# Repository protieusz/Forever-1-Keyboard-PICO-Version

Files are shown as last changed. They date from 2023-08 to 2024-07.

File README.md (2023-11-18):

# Forever-1-Keyboard-PICO-Version
Forever-1 Inspired by policum's GRIN QUERN 38 keys keyboard powered by PICO Raspberry with giant 60mm rotary encoder with 40mm Cirque trackpad

Got featured on [Keyboard Builder's Digest (KBD News)](https://kbd.news/FOREVER-1-2107.html)

This pcb design is proudly sponsored by PCBWay, your solution to all your prototype pcb needs. PCBWay customer service dept are very proactive on making things right if there are issues with the production.  

Part of the design was assisted by policum, the designer for GRIN QUERN which the Forever-1 is inspired from.

**Update Nov 18, 2023:** The gerber production files have been uploaded. Print at your own risk. Please follow the license useage and don't be an ass.  Lots of advance soldering technique is required. No support will be given.
BOM list is inside the build guide excel file along with the links.

Update Aug 30, 2023: PCB from PCBWay has arrived. Keyboard has been assembled except for the case and waiting for the nylon knob print.

~~This design will be close source for now. It might be release in the future.~~

Final Build Sept 1, 2023

















Partial build Aug 30, 2023





















































PCB is currently is in print as of Aug 21, 2023.  Build pictures coming soon.

A mock up of the final product






















# License

</a></p>

You are free to:

Share — copy and redistribute the material in any medium or format

Adapt — remix, transform, and build upon the material

The licensor cannot revoke these freedoms as long as you follow the license terms.
Under the following terms:

Attribution — You must give appropriate credit, provide a link to the license, and indicate if changes were made. You may do so in any reasonable manner, but not in any way that suggests the licensor endorses you or your use.

NonCommercial — You may not use the material for commercial purposes.

ShareAlike — If you remix, transform, or build upon the material, you must distribute your contributions under the same license as the original.

No additional restrictions — You may not apply legal terms or technological measures that legally restrict others from doing anything the license permits.

Forever-1 by ProtieusKeebs is licensed under [CC BY-NC-SA 4.0](https://creativecommons.org/licenses/by-nc-sa/4.0/?ref=chooser-v1)

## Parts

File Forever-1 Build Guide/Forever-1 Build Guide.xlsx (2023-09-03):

FOREVER-1 Build Guilde
BOM List:
Item Number | Item Name | Part Number | Web Link
1 | Raspberry PICO mcu | Green USB C | Pico Raspberry Green USB C (https://www.aliexpress.com/item/1005003371056277.html)
2 | Bourn’s PER60 mm Encoder | PER601-P117-N0015 | Encoders Encoders 60MM LOW PROFILE ENCODER (https://www.mouser.ca/ProductDetail/652-PER601P117N0015)
3 | Cirque 40mm Trackpad | TM040040-2024-303 | Cirque 40mm trackpad (https://www.mouser.ca/ProductDetail/355-TM0400402024-303)
4 | SK6812 mini e RGB (3-4 pcs) optional |  | SK6812 mini e (https://www.aliexpress.com/item/1005004249903121.html)
5 | Wires 26 AWG (5meters, recommend getting 6 different colors) |  | Wires 26 AWG 5 meters (https://www.aliexpress.com/item/1005001869989189.html)
6 | Diodes smd 38 pcs |  | Diodes SMD 1N4148 SOD-123 (https://www.aliexpress.com/item/1005002936094696.html)
7 | 38 Switches |  | Your choice
8 | Cherry/OEM keycaps (Due to rotations, MT3 profiles will rub) |  | Your choice
9 | 3M double side tape for securing the trackpad to the support |  | Amazon or Aliexpress. Common product
10 | Acrylic glue or whatever glue to secure the tackpad support structure to the pcb |  | Acrylic glue (https://www.aliexpress.com/item/1005004560711687.html)
11 | M2x2x3.2 hot inserts (11pcs) |  | M2x2x3.2 Hot Inserts (https://www.aliexpress.com/item/1005004629326869.html)
12 | M2 5mm screws (11pcs) |  | M2 5mm screws (https://www.aliexpress.com/item/32976597416.html)

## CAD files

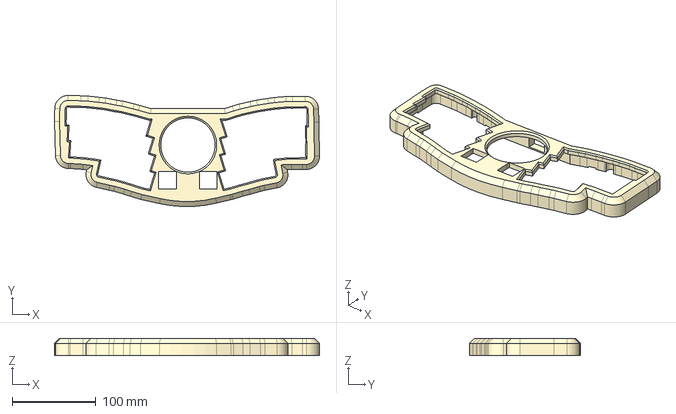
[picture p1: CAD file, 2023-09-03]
Forever-1 Full Case.step
316.6 x 132.6 x 20.9 mm

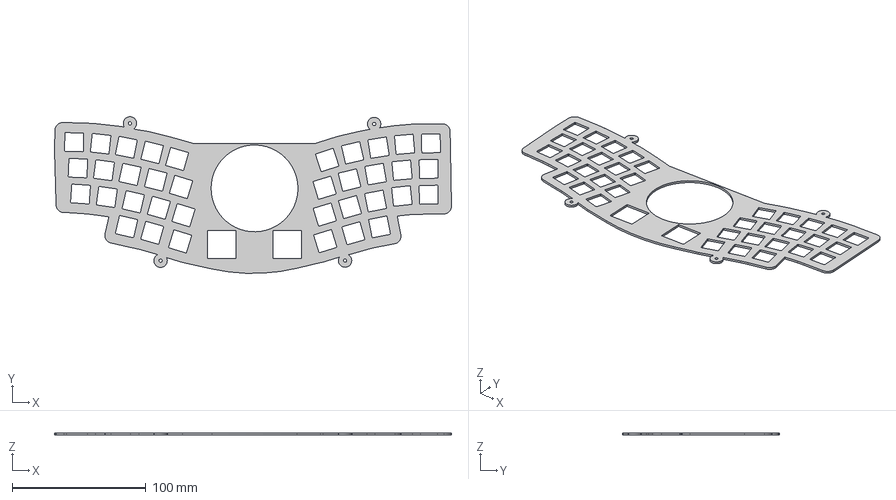
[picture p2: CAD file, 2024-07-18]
Full Switch Plate/Forever-1 Full Switch Plate.step
296.6 x 117.0 x 1.60 mm

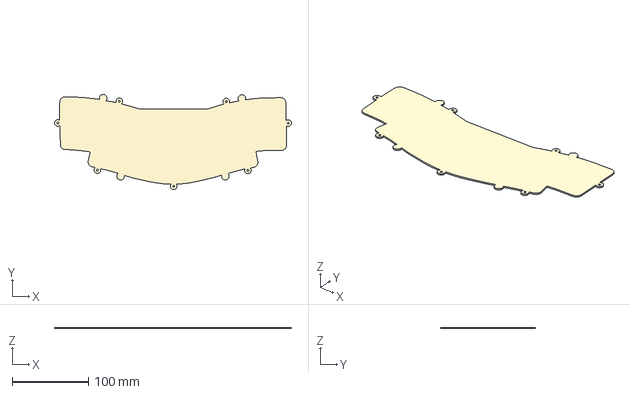
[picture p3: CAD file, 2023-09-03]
Forever-1 full bottom plate.step
311.6 x 125.2 x 1.60 mm

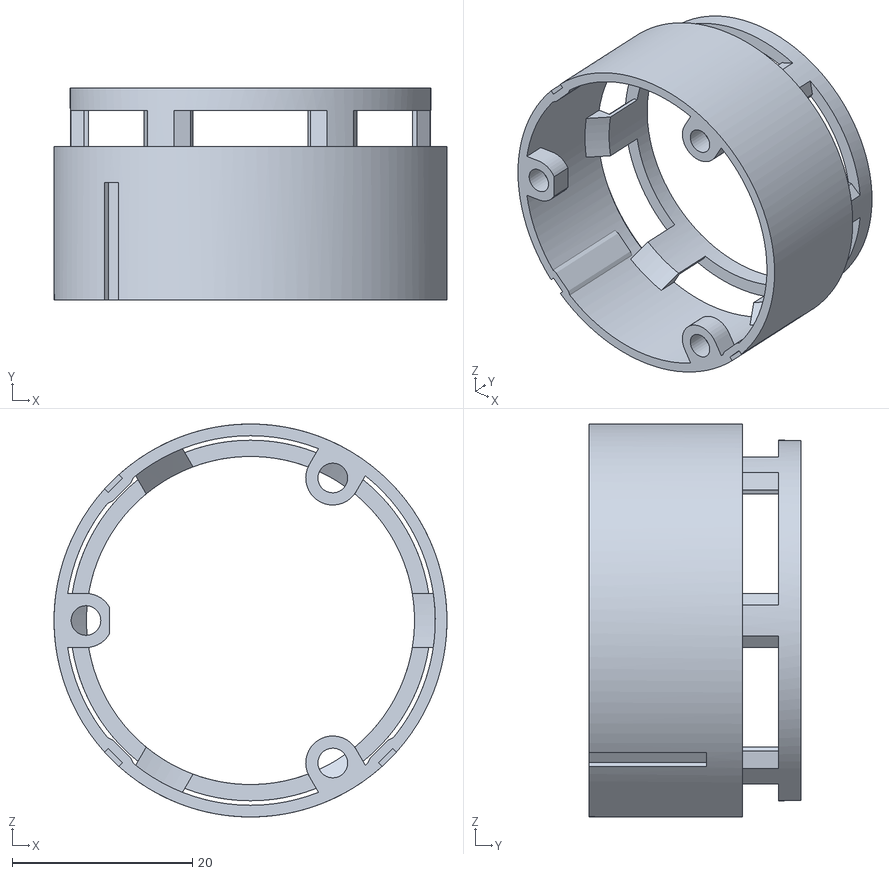
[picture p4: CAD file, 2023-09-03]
Center Piece Support Parts/Bournsper60knobstand.stl
43.6 x 23.5 x 43.6

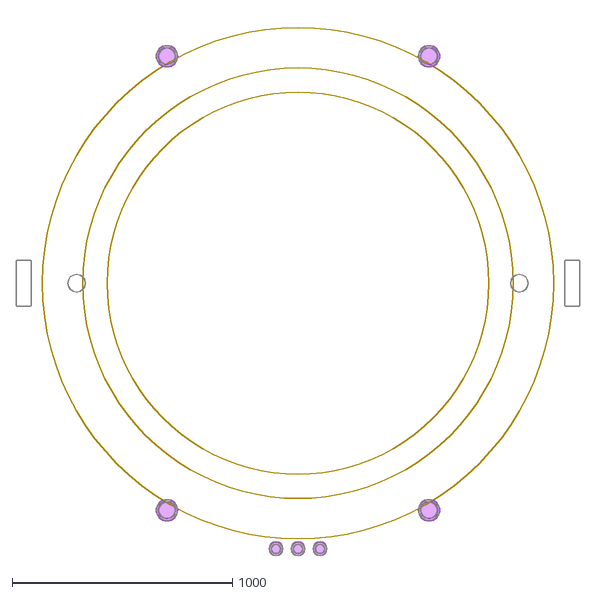
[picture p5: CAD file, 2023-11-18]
GerberRev1/PER601_2023-08-14.dxf
2557.0 x 2447.8

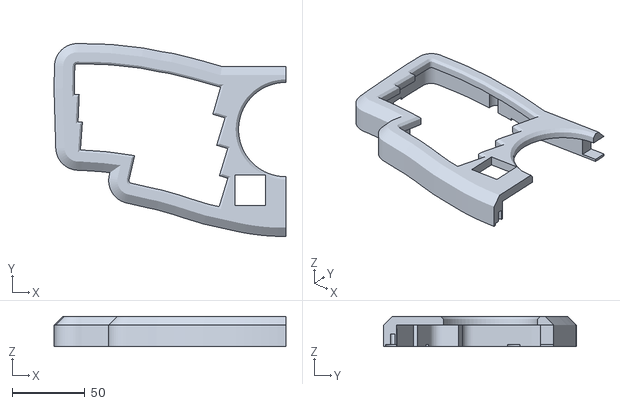
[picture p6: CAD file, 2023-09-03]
Split STLs/Forever1CaseLEFT.stl
159.6 x 132.7 x 20.9

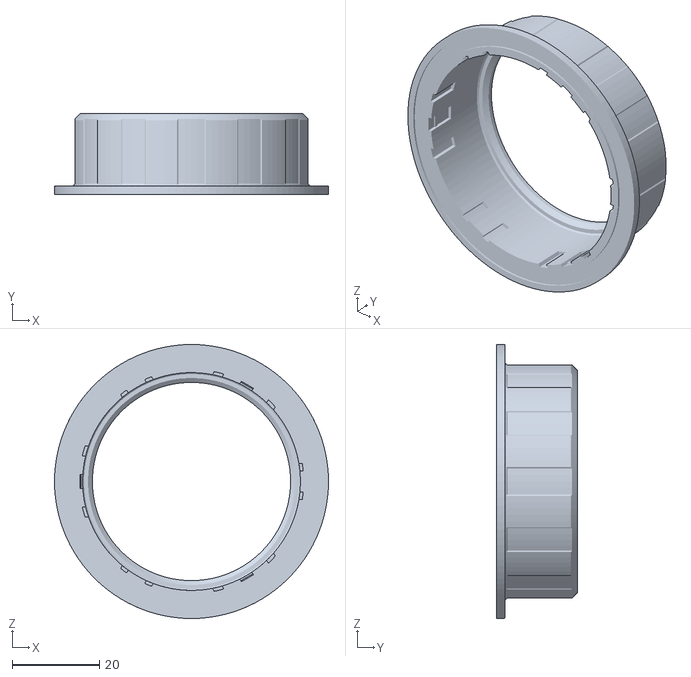
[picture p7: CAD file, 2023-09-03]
Center Piece Support Parts/Bournsper60knob.stl
62.9 x 18.6 x 62.9

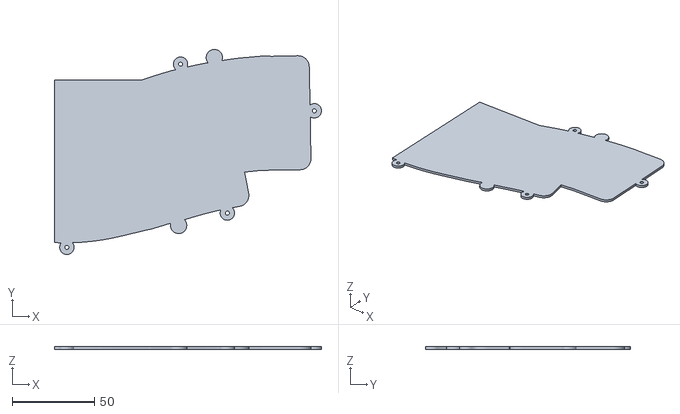
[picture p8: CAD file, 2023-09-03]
Split STLs/Forever1BottomplateRIGHT.stl
162.4 x 124.8 x 1.60

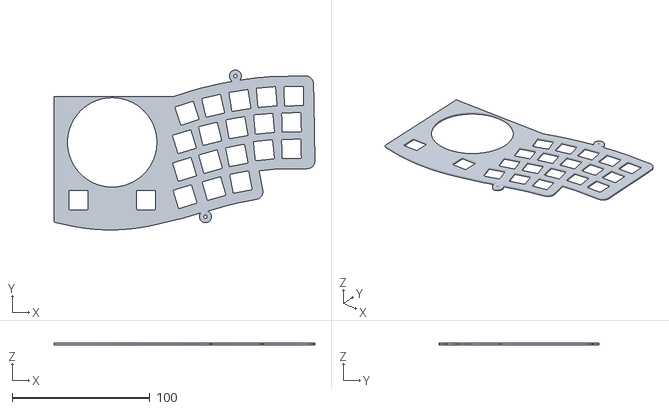
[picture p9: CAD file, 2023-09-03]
Split STLs/Forever1SwitchPlateRIGHT.stl
189.4 x 116.0 x 1.50

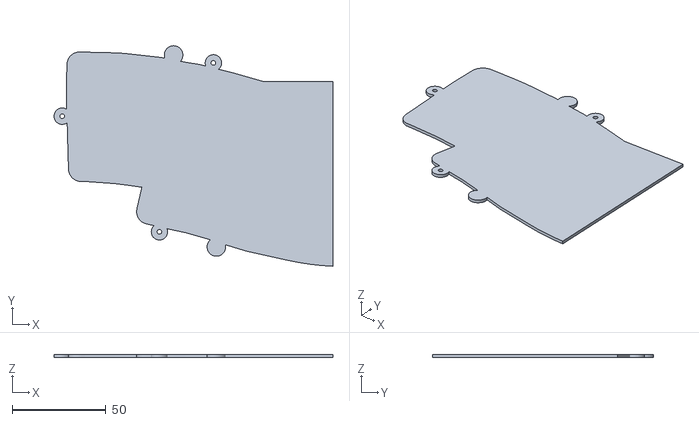
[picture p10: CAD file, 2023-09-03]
Split STLs/Forever1BottomplateLEFT.stl
149.2 x 117.9 x 1.60

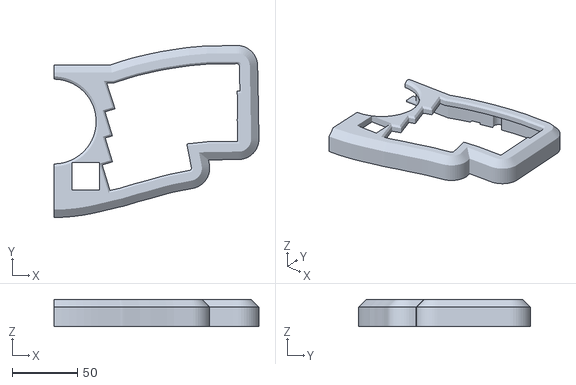
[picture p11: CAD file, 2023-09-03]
Split STLs/Forever1CaseRIGHT.stl
157.0 x 131.8 x 20.9

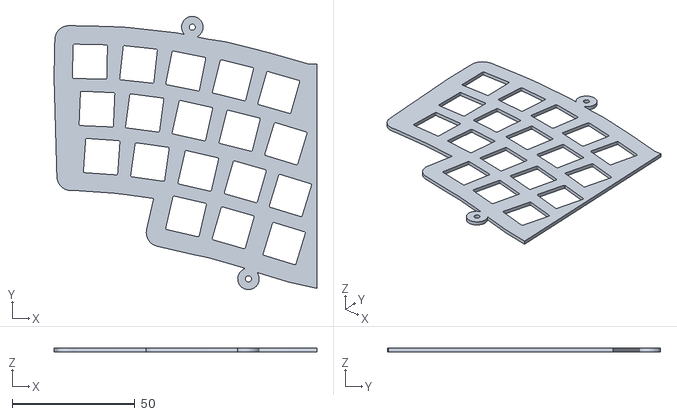
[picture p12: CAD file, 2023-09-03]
Split STLs/Forever1SwitchPlateLEFT.stl
107.2 x 111.4 x 1.50

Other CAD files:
Full Switch Plate/Forever-1 Full Switch Plate.stl

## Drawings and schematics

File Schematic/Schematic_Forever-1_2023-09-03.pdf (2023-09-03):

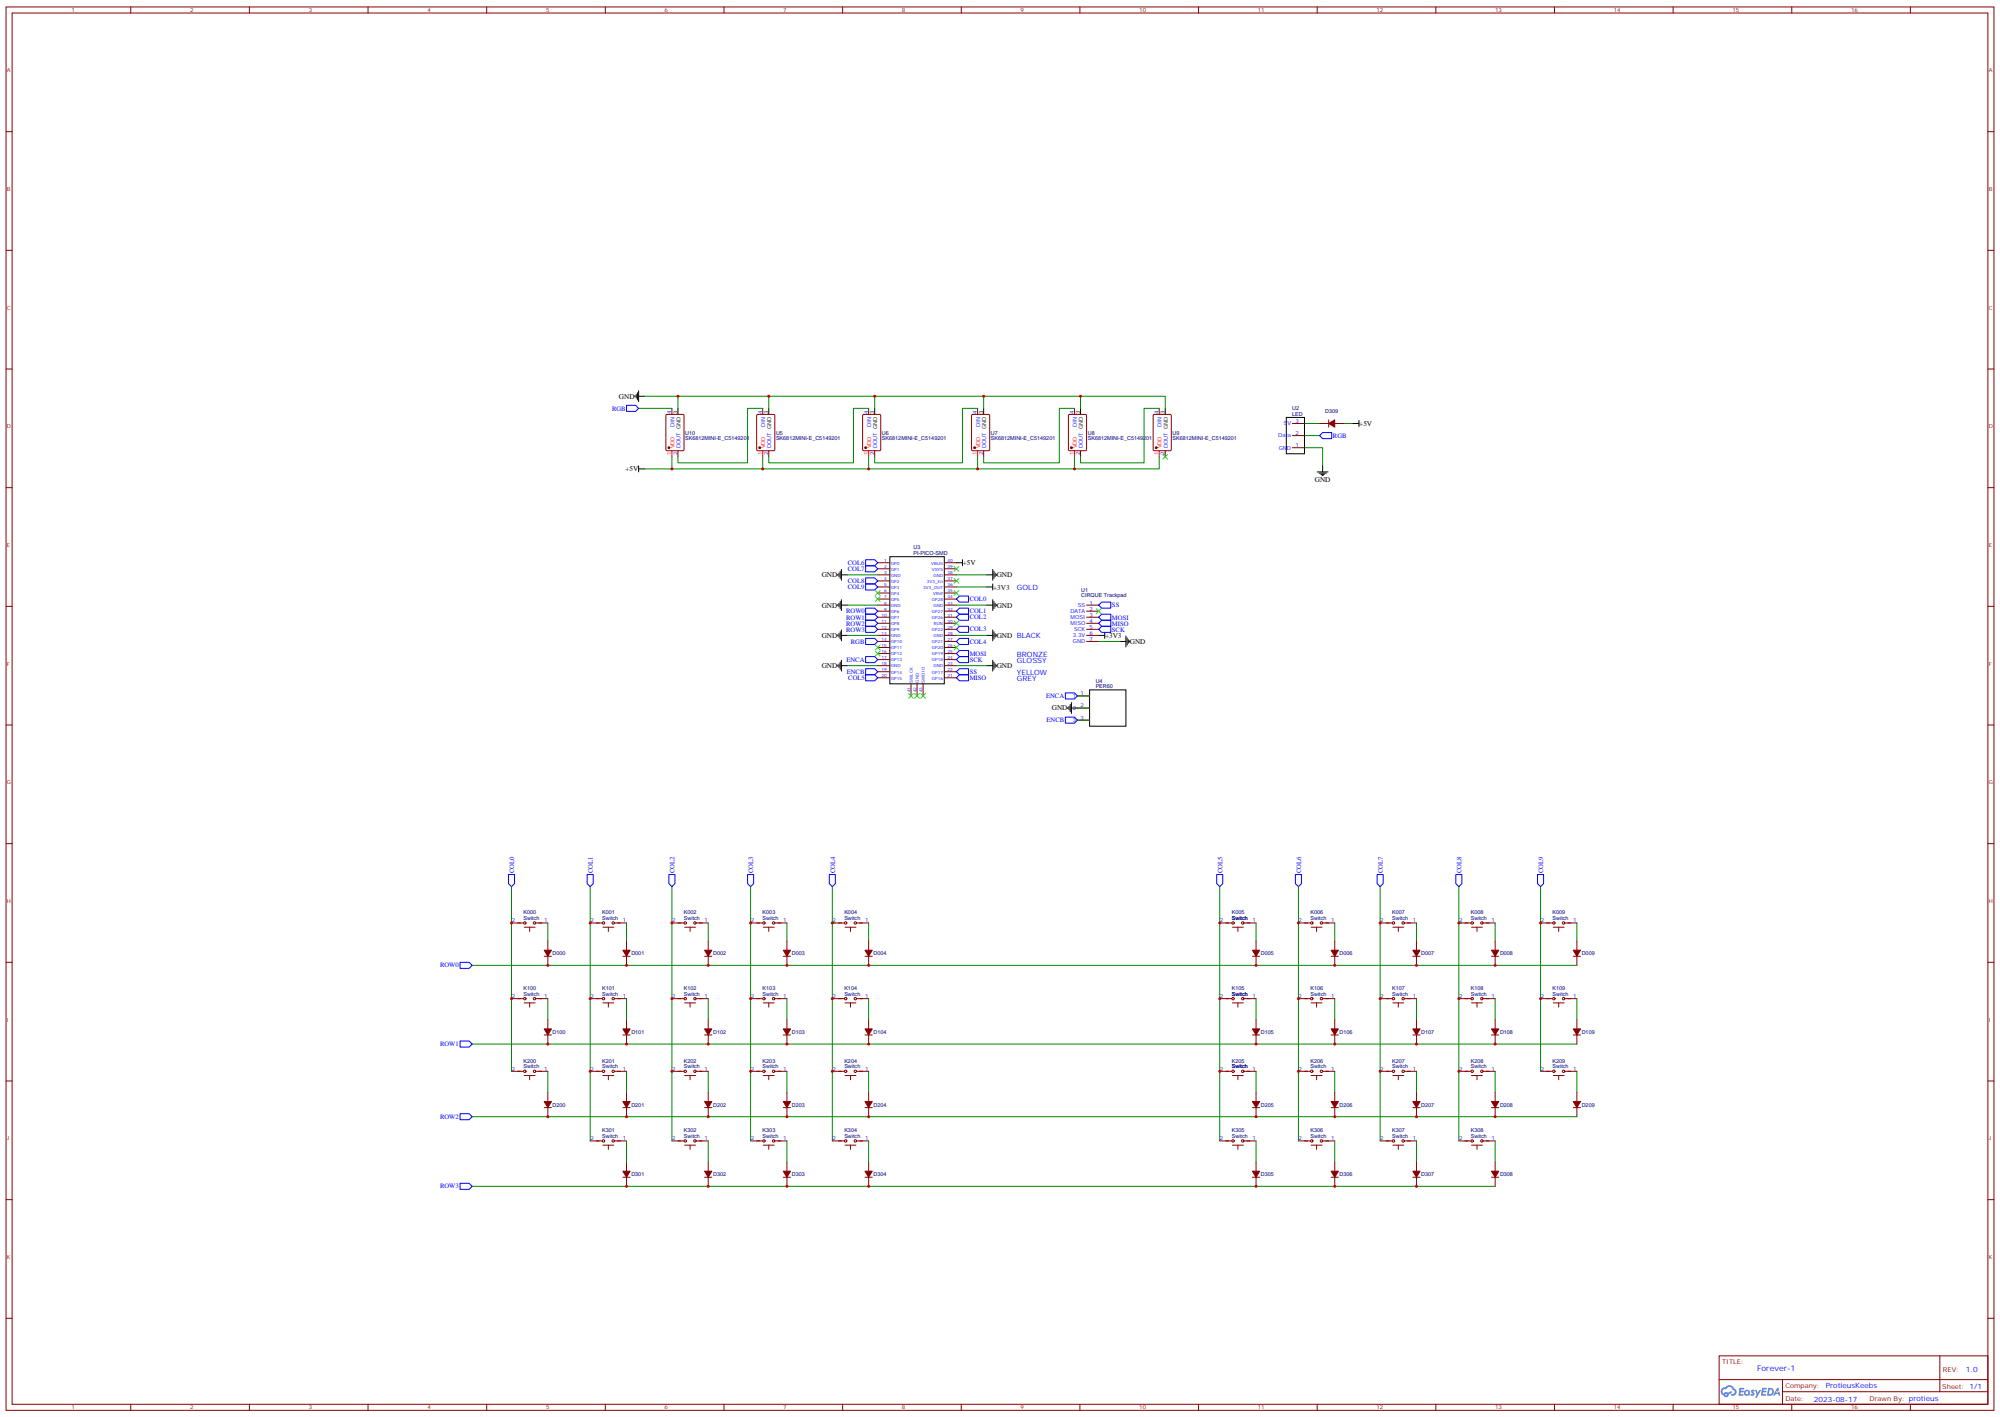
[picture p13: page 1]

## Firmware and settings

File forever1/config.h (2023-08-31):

/*
 * Copyright 2021 Quentin LEBASTARD <qlebastard@gmail.com>
 * Copyright 2022 Charly Delay <charly@codesink.dev> (@0xcharly)
 *
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
 * You should have received a copy of the GNU General Public License
 * along with this program.  If not, see <http://www.gnu.org/licenses/>.
 */

#pragma once

#define RP2040_BOOTLOADER_DOUBLE_TAP_RESET // Activates the double-tap behavior
#define RP2040_BOOTLOADER_DOUBLE_TAP_RESET_TIMEOUT 200U // Timeout window in ms in which the double tap can occur.

#ifdef COMBO_ENABLE
//#    define COMBO_COUNT 6
#    define COMBO_TERM 200
#endif

/* Pointing device configuration. */

// Limits the frequency that the sensor is polled for motion.
#define POINTING_DEVICE_TASK_THROTTLE_MS 10

// Adjust trackpad rotation.
#define POINTING_DEVICE_ROTATION_90

// Configure for the Cirque model used on the Dilemma.
#define CIRQUE_PINNACLE_DIAMETER_MM 40
#define CIRQUE_PINNACLE_CURVED_OVERLAY
#define POINTING_DEVICE_GESTURES_SCROLL_ENABLE // Circular scroll. in this mode enables circular scroll. Touch originating in outer ring can trigger scroll by moving along the perimeter. Near side triggers vertical scroll and far side triggers horizontal scroll.
#define CIRQUE_PINNACLE_ATTENUATION EXTREG__TRACK_ADCCONFIG__ADC_ATTENUATE_3X


//Drasha settings
//#define CIRQUE_PINNACLE_TAP_ENABLE //Enable tap to "left click".
//#define POINTING_DEVICE_GESTURES_CURSOR_GLIDE_ENABLE

//#define CIRQUE_PINNACLE_SECONDARY_TAP_ENABLE //Tap in upper right corner (half of the finger needs to be outside of the trackpad) of the trackpad will result in "right click".

/* Cirque trackpad. */
#define SPI_SCK_PIN GP18
#define SPI_MOSI_PIN GP19
#define SPI_MISO_PIN GP16
#define POINTING_DEVICE_CS_PIN GP17

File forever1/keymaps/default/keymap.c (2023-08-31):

 // Copyright 2023 %YOUR_FULL_NAME% (@%YOUR_GITHUB_USERNAME%)
// SPDX-License-Identifier: GPL-2.0-or-later

#include QMK_KEYBOARD_H

enum combo_events {
  COMBO_DEL,
  COMBO_ESC,
  COMBO_LENGTH
};
uint16_t COMBO_LEN = COMBO_LENGTH;

const uint16_t PROGMEM combo_del[] = {KC_Y, KC_H, COMBO_END};
const uint16_t PROGMEM combo_esc[] = {KC_T, KC_G, COMBO_END};

combo_t key_combos[] = {
  [COMBO_DEL] = COMBO(combo_del, KC_DEL),
  [COMBO_ESC] = COMBO(combo_esc, KC_ESC),
};

layer_state_t layer_state_set_user(layer_state_t state) {
    return update_tri_layer_state(state, 1, 2, 3);
} 

enum layer_names {
  _BASE,
  _FN1,
  _FN2,
  _FN3
};

const uint16_t PROGMEM keymaps[][MATRIX_ROWS][MATRIX_COLS] = {
    
    [_BASE] = LAYOUT(
        KC_Q,         KC_W, KC_E,    KC_R,    KC_T,                                           KC_Y,          KC_U,          KC_I,     KC_O,   KC_P,
        KC_A,         KC_S, KC_D,    KC_F,    KC_G,                                           KC_H,          KC_J,          KC_K,     KC_L,   KC_SCLN,
        LSFT_T(KC_Z), KC_X, KC_C,    KC_V,    KC_B,                                           KC_N,          KC_M,          KC_COMMA, KC_DOT, RSFT_T(KC_SLSH),
                            KC_LCTL, KC_LGUI, LT(1,KC_BSPC),   KC_MS_BTN2,    KC_MS_BTN1,     LT(2,KC_SPC),   (KC_ENT),      KC_LALT
    ),
    [_FN1] = LAYOUT(
        KC_1,    KC_2,    KC_3,    KC_4,    KC_5,                            KC_6,     KC_7,    KC_8,    KC_9,    KC_0,
        KC_TAB,  _______, _______, _______, _______,                         KC_MINS,  KC_EQL,  KC_LBRC, KC_RBRC, KC_QUOT,
        _______, _______, KC_MUTE, KC_VOLD, KC_VOLU,                         KC_TILD,  KC_GRV,  _______, _______, KC_BSLS,
                          _______, _______, _______,     _______, _______,   _______,  _______, _______
    ),
    [_FN2] = LAYOUT(
        KC_EXLM, KC_AT,   KC_HASH, KC_DLR,  KC_PERC,                         KC_CIRC, KC_AMPR, KC_ASTR, KC_LPRN, KC_RPRN,
        RGB_VAI,  RGB_SAI,    RGB_HUI,    RGB_SPI,   RGB_MOD,                RGB_TOG,  _______,  _______,   _______, _______,
        RGB_VAD,  RGB_SAD,    RGB_HUD,    RGB_SPD,   RGB_RMOD,               KC_ACL0,  KC_ACL1, KC_ACL2, _______, _______,
                          _______, _______, _______,     _______, _______,   _______,  _______, _______
    ),
    [_FN3] = LAYOUT(
        _______, KC_UP, _______, _______, _______,                         KC_F1,   KC_F2,   KC_F3,   KC_F4,   KC_PSCR,
        KC_LEFT, KC_DOWN, KC_RIGHT, _______, _______,                      KC_F5,   KC_F6,   KC_F7,   KC_F8,   KC_F9,
        _______, _______, _______, _______, _______,                       KC_F10,  KC_F11,  KC_F12,  _______, _______,
                          _______, _______, _______,     _______, _______,   _______, _______, _______
    )
};

//bool encoder_update_user(uint8_t index, bool clockwise) {
    //if (index == 0) {
        //if (clockwise) {
            //tap_code(KC_VOLD);
            //tap_code(KC_MS_WH_UP);
        //} else {
            //tap_code(KC_VOLU);
            //tap_code(KC_MS_WH_DOWN);
        //}
    //}
    //return true;
//}

#if defined(ENCODER_MAP_ENABLE)
const uint16_t PROGMEM encoder_map[][NUM_ENCODERS][2] = {
    [0] =  { ENCODER_CCW_CW(KC_MS_WH_UP, KC_MS_WH_DOWN)  },
    [1] =  { ENCODER_CCW_CW(KC_MS_WH_LEFT, KC_MS_WH_RIGHT)  },
    [2] =  { ENCODER_CCW_CW(KC_PGUP, KC_PGDN)  },
    [3] =  { ENCODER_CCW_CW(KC_VOLD, KC_VOLU)  } 
    //[4] =  { ENCODER_CCW_CW(XXXXXXX, XXXXXXX) }
};
#endif

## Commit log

2023-09-03 Add BOM list
    Will add steps soon.
    [Forever-1 Build Guide.xlsx]
2023-09-03 Add schematic
2023-09-03 Add knob and trackpart support 3D parts
    [Bournsper60knob.stl, Bournsper60knobstand.stl]
2023-09-03 Case & Switch plate STL
    Split STLs for easier installation.
    [Forever1BottomplateLEFT.stl, Forever1BottomplateRIGHT.stl, Forever1CaseLEFT.stl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]
2023-09-03 Case & Bottom STEP file
    [Forever-1 Full Case.step, Forever-1 full bottom plate.step]
2023-11-18 Gerber production files
2023-11-18 PER60 dxf for pcb
    [PER601_2023-08-14.dxf]
2024-07-18 Full Switch plate files
    [Forever-1 Full Switch Plate.step, Forever-1 Full Switch Plate.stl]

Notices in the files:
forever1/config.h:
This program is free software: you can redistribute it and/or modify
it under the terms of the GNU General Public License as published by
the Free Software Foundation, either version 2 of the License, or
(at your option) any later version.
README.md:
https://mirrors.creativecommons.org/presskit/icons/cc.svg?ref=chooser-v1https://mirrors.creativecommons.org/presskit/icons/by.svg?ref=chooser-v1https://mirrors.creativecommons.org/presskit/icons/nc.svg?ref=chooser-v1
